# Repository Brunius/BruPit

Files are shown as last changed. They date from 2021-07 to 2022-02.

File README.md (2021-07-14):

# BruPit

A flight simulator project.

BruPit started because I went _"Gosh, Cougar MFDs are expensive for what you get"_. Since then it's grown, much more than I expected it to. I never expected to need to do proper software engineer stuff like sequence diagrams and READMEs. This repository is organised as best I can; I think it's fairly clear where stuff is, but I may be wrong. In short:

## ECAD

Contains _electrical_ CAD items. These are Circuit Diagrams and PCB layouts. All items are designed with kicad.

## MCAD

Contains _mechanical_ CAD items. These are mostly enclosures for stuff. All items are designed with Solidworks (sorry, FreeCAD - I love you, but I really wanted an assembly workbench).

## Programs

Contains the software you need. These are intended to be loaded using the Arduino IDE, though other IDEs may work.

## Documentation

Contains any documentation, mostly surrounding the software. This is stuff you _shouldn't_ need as a home user, but might want if you're modifying the software.

For any further questions or queries, you can contact me at brunius@brunius.me or Brunius#5625 on Discord.

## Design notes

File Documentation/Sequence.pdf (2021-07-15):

## Child Discovery Process (setup)

Mother | Child 1 | Child 2

childSetup()

Write 0x69
Request 2 bytes

byte 1: no. of buttons
byte 2: no. of rotaries
childSetup() | Ask what types | of input the
child has, and how many it has
| childSetup() Ask what types child has, and how many it has childSetup() | of input the
Write | 0x69
Request | 2 bytes
byte 1: no. byte 2: no. | of buttons of rotaries

This process continues until all i2c addresses have been polled. Addresses are polled from low to high, with buttons allocated on the same basis. This ensures that the same boards, connected to the same host, represent the same buttons to the OS.

1

## Data Request Process (loop)

Mother | Child 1 | Child 2

getInput()

Request 1 byte

byte 1: state of buttons

getInput() | Ask which inputs are active Child 1 has 8 buttons
| getInput() Ask which inputs are active Child 2 has 16 buttons and 1 rotary getInput()
Request | 3 bytes
byte 1: state of buttons byte 2: state of buttons byte 3: | rotary 1

This process cycles through all known active i2c addresses (discovered in child discovery process). Number of bytes varies depending on number of buttons and number of rotaries - bytes 1 to x are always state of buttons, depending on how many buttons are present. buttons x + 1 onward are rotaries

2

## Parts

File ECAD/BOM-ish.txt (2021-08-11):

Childboard 1:

	J1: Unpopulated
	J2: 1x4 2.54mm SMD Male
	J3: 1x4 2.54mm SMD Male
	J4: 1x4 2.54mm SMD Male

	U1: ATmega168V-AU

	R1: 330
	R2: 330
	R3: 330
	R4: 330	
	R5: 330

	C1: 100nF

Childboard 2 + 3:

	J1: Unpopulated
	J2: 1x4 2.54mm SMD Male
	J3: 1x4 2.54mm SMD Male
	J4: Unpopulated
	J5: 1x4 2.54mm SMD Male
	J6: 1x4 2.54mm SMD Male

	U1: ATmega168V-AU
	U2: ATmega168V-AU

	R1: 330
	R5: 330

	C1: 100nF
	C2: 100nF

Child MFD:

	J1: Unpopulated
	J2: 1x4 2.54mm SMD Male

	U1: ATmega168V-AU

	R1: 10K
	R5: 330
	R8: 330

	C4: 100nF

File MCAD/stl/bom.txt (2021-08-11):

low rate initial production:
1x frontside
1x backside

full rate:
5x frontside
5x backside
100x square button
20x long button

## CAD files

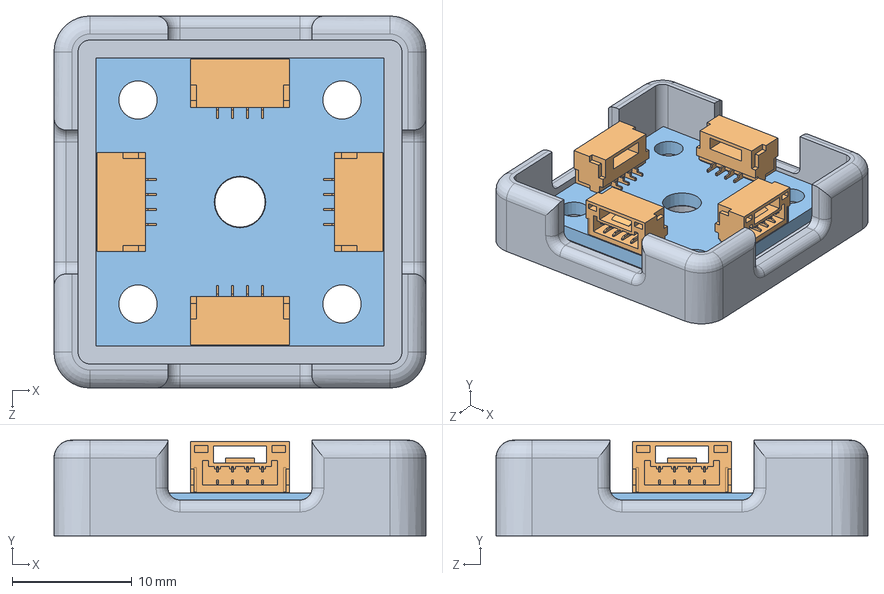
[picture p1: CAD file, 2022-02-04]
MCAD/Junction-Assembly.SLDASM
31.0 x 8.00 x 31.0 mm
Junction-Back
SOLID.step x 4
COMPOUND.step

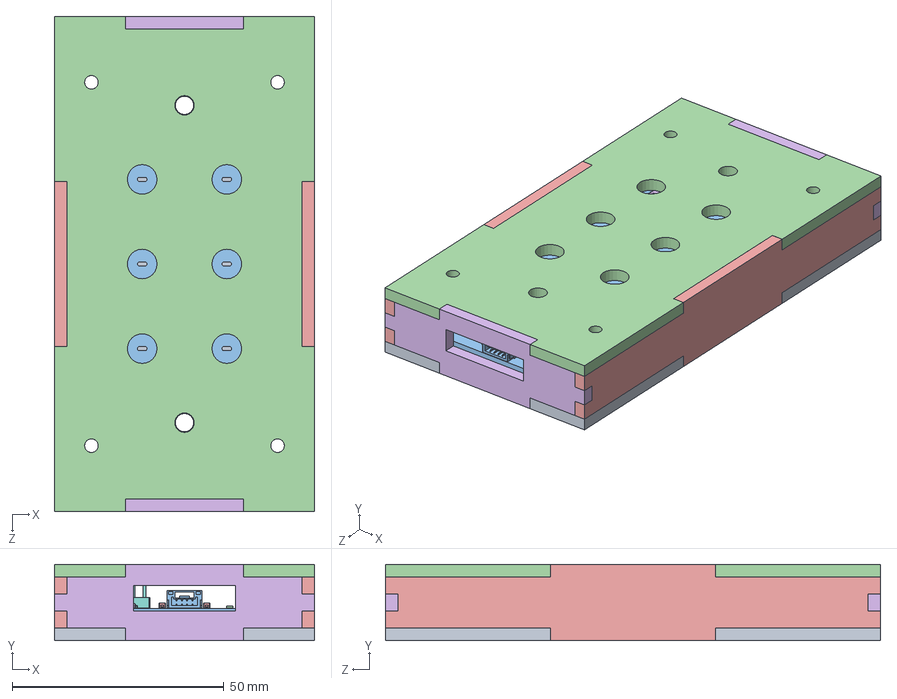
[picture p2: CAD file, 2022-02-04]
MCAD/LaserCut/SwitchBox-Assembly.SLDASM
61.5 x 18.0 x 117.0 mm
ButtonBox-Bottomplate
UFC-Washer x 2
SOLID.step x 2
SOLID-0.step
SOLID-1.step x 6
SOLID-2.step
SOLID-3.step
SOLID-4.step
SOLID-5.step
SOLID-6.step
COMPOUND.step
SwitchBox-Faceplate
SwitchBox-Sideplate x 2
SwitchBox-Topplate x 2

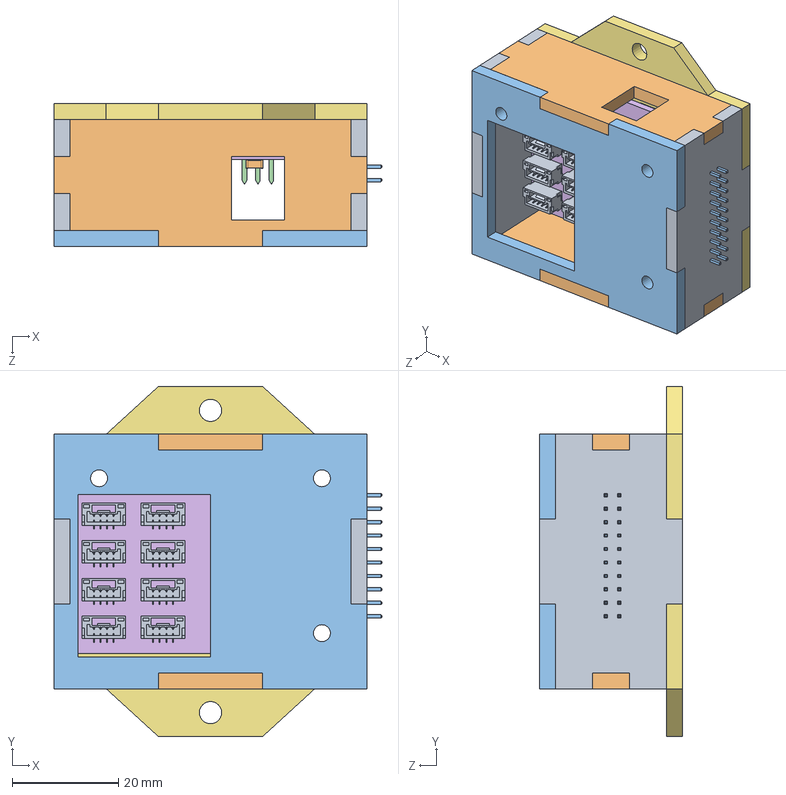
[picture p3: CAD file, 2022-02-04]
MCAD/Master-Assembly.SLDASM
61.8 x 66.0 x 27.0 mm
SOLID.step x 8
SOLID-0.step
SOLID-1.step
SOLID-2.step
SOLID-3.step x 2
COMPOUND.step
Master-Back
UFC-Washer x 2
Master-Sides x 2
Master-BottomTop x 2
Master-Front

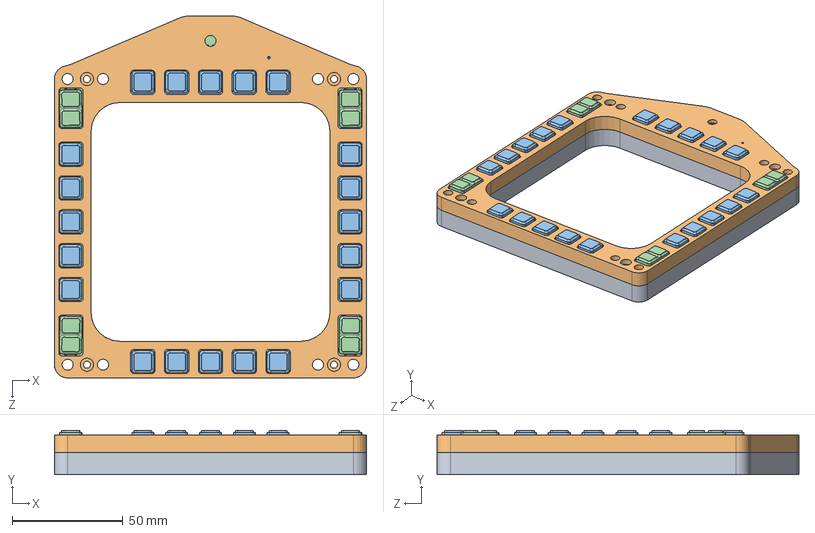
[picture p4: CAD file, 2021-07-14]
MCAD/MFD-Assembly.SLDASM
141.2 x 19.9 x 163.7 mm
Backside
Frontside
SquareButton x 20
LongButton x 4
SOLID.step
SOLID-0.step
SOLID-1.step
SOLID-2.step x 4
SOLID-3.step
SOLID-4.step x 28
SOLID-5.step
COMPOUND.step

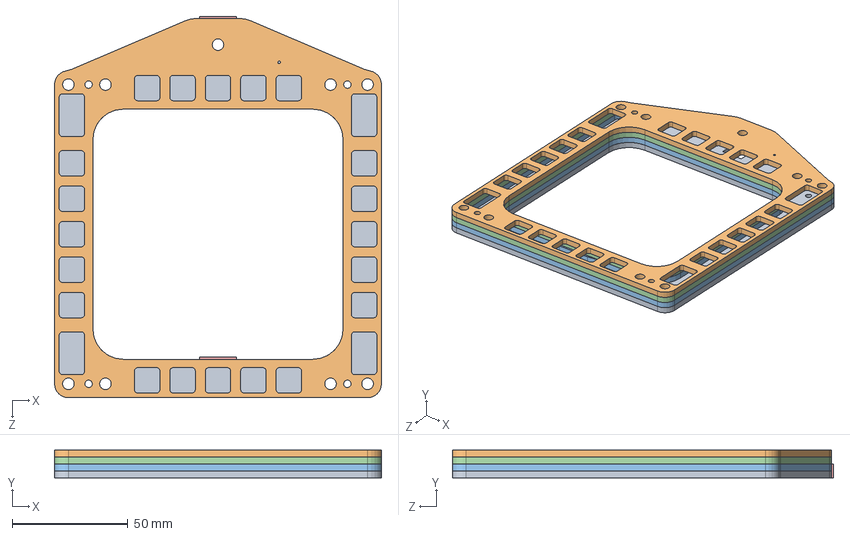
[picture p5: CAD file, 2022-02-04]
MCAD/LaserCut/MFD-Assembly.SLDASM
141.2 x 12.0 x 164.7 mm
MFD-Layer1
MFD-Layer4
MFD-Layer2
MFD-Layer3
MFD-locking x 2

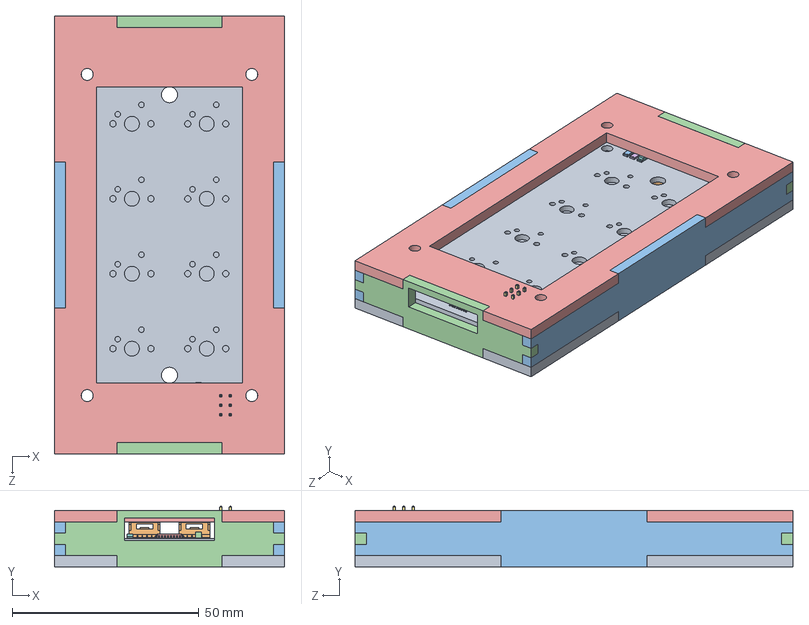
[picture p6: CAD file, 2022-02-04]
MCAD/LaserCut/ButtonBox-Assembly.SLDASM
61.5 x 16.2 x 117.0 mm
ButtonBox-Bottomplate
SOLID.step x 2
SOLID-0.step
SOLID-1.step
SOLID-2.step
SOLID-3.step
SOLID-4.step
SOLID-5.step
COMPOUND.step
UFC-Washer x 2
UFC-Sideplate x 2
ButtonBox-Topplate x 2
ButtonBox-Faceplate

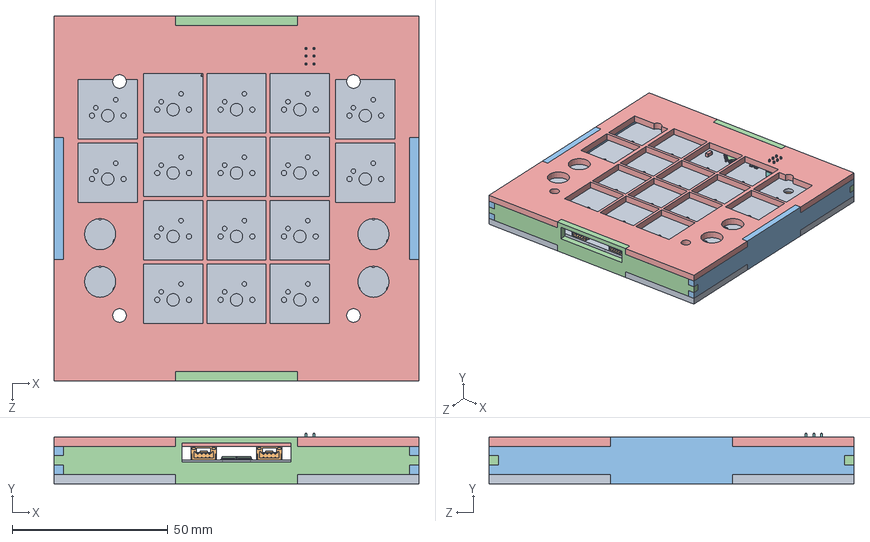
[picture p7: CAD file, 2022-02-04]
MCAD/LaserCut/UFC-Assembly.SLDASM
117.0 x 16.2 x 117.0 mm
UFC-Backplate
SOLID.step x 2
SOLID-0.step
SOLID-1.step
SOLID-2.step
SOLID-3.step x 5
SOLID-4.step
SOLID-5.step
COMPOUND.step
UFC-Washer x 4
UFC-Sideplate x 2
UFC-BottomPlate x 2
UFC-Faceplate

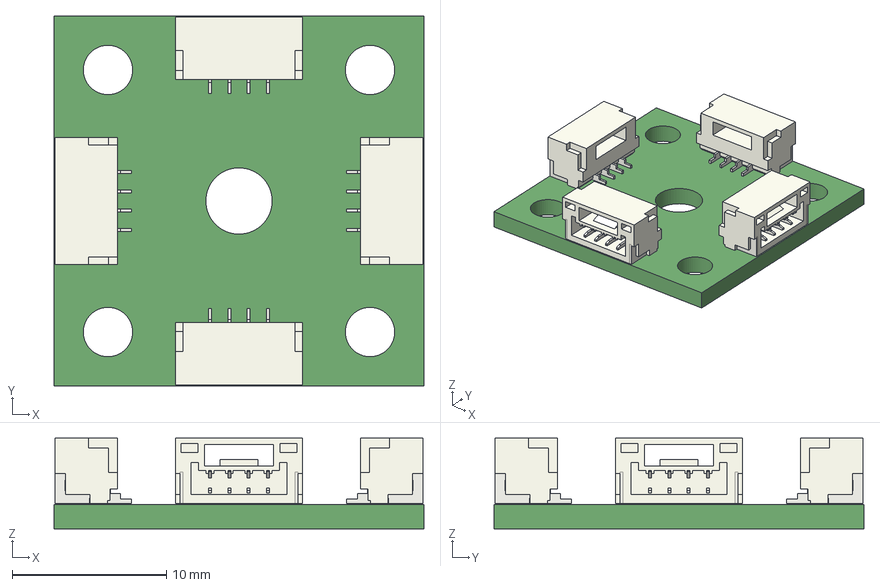
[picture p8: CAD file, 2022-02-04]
ECAD/junction/junction.step
24.0 x 24.0 x 5.89 mm

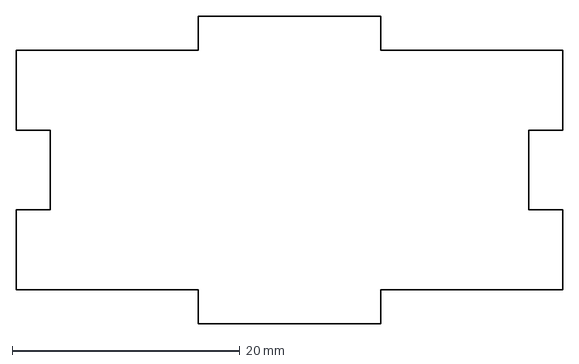
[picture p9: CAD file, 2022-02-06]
MCAD/LaserCut/Master-Sides.DXF
48.0 x 27.0 mm

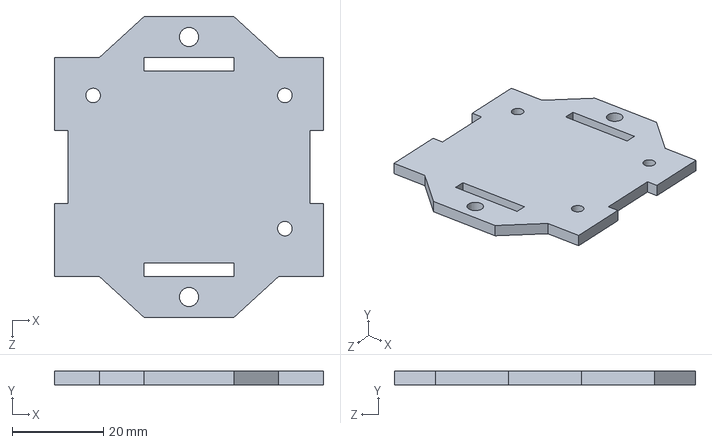
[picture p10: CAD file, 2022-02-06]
MCAD/Master-Back.SLDPRT
59.0 x 3.00 x 66.0 mm

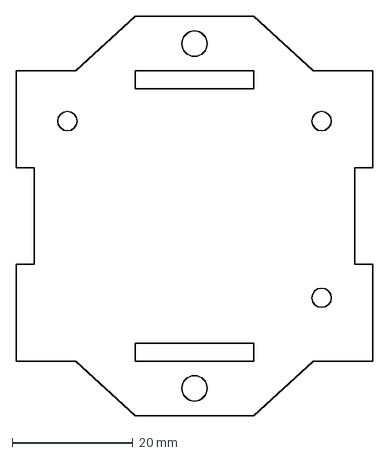
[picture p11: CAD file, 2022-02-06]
MCAD/LaserCut/Master-Back.DXF
59.0 x 66.0 mm

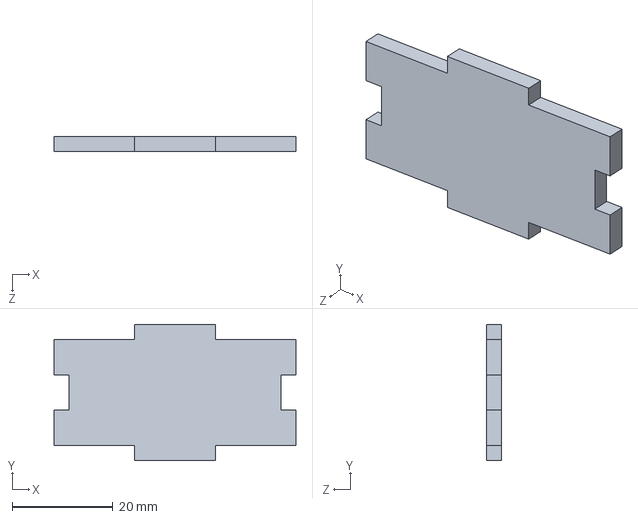
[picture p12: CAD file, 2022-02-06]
MCAD/Master-Sides.SLDPRT
48.0 x 27.0 x 3.00 mm

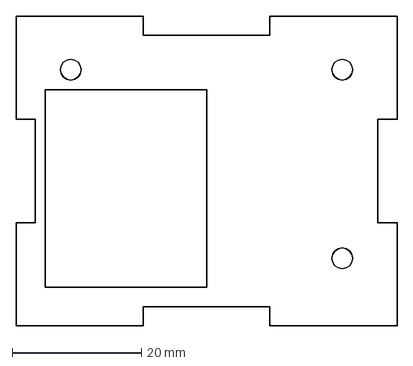
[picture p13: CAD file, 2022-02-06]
MCAD/LaserCut/Master-Front.DXF
59.0 x 48.0 mm

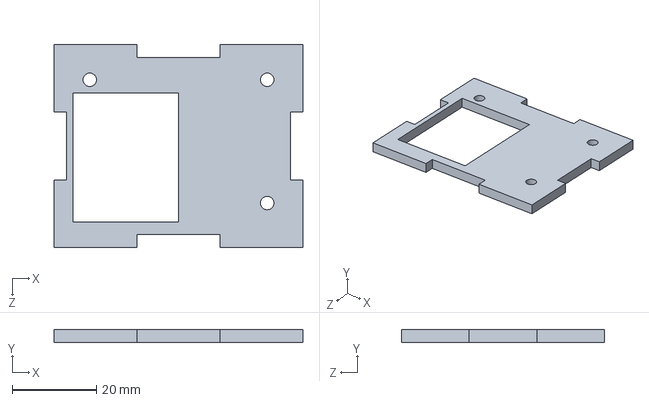
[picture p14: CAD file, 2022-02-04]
MCAD/Master-Front.SLDPRT
59.0 x 3.00 x 48.0 mm

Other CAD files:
MCAD/LaserCut/ButtonBox-Bottomplate.SLDPRT
MCAD/Master-BottomTop.SLDPRT
MCAD/Junction-Back.SLDPRT
MCAD/LaserCut/Master-BottomTop.DXF
MCAD/Backside.SLDPRT
MCAD/Frontside.SLDPRT
MCAD/LaserCut/ButtonBox-Bottomplate.DXF
MCAD/LaserCut/ButtonBox-Faceplate.DXF
MCAD/LaserCut/ButtonBox-Faceplate.SLDPRT
MCAD/LaserCut/ButtonBox-Topplate.DXF
MCAD/LaserCut/ButtonBox-Topplate.SLDPRT
MCAD/LaserCut/MFD-Layer1.DXF
MCAD/LaserCut/MFD-Layer1.SLDPRT
MCAD/LaserCut/MFD-Layer2.DXF
MCAD/LaserCut/MFD-Layer2.SLDPRT
MCAD/LaserCut/MFD-Layer3.DXF
MCAD/LaserCut/MFD-Layer3.SLDPRT
MCAD/LaserCut/MFD-Layer4.DXF
MCAD/LaserCut/MFD-Layer4.SLDPRT
MCAD/LaserCut/MFD-locking.DXF
MCAD/LaserCut/MFD-locking.SLDPRT
MCAD/LaserCut/SwitchBox-Faceplate.DXF
MCAD/LaserCut/SwitchBox-Faceplate.SLDPRT
MCAD/LaserCut/SwitchBox-Sideplate.DXF
MCAD/LaserCut/SwitchBox-Sideplate.SLDPRT
MCAD/LaserCut/SwitchBox-Topplate.DXF
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

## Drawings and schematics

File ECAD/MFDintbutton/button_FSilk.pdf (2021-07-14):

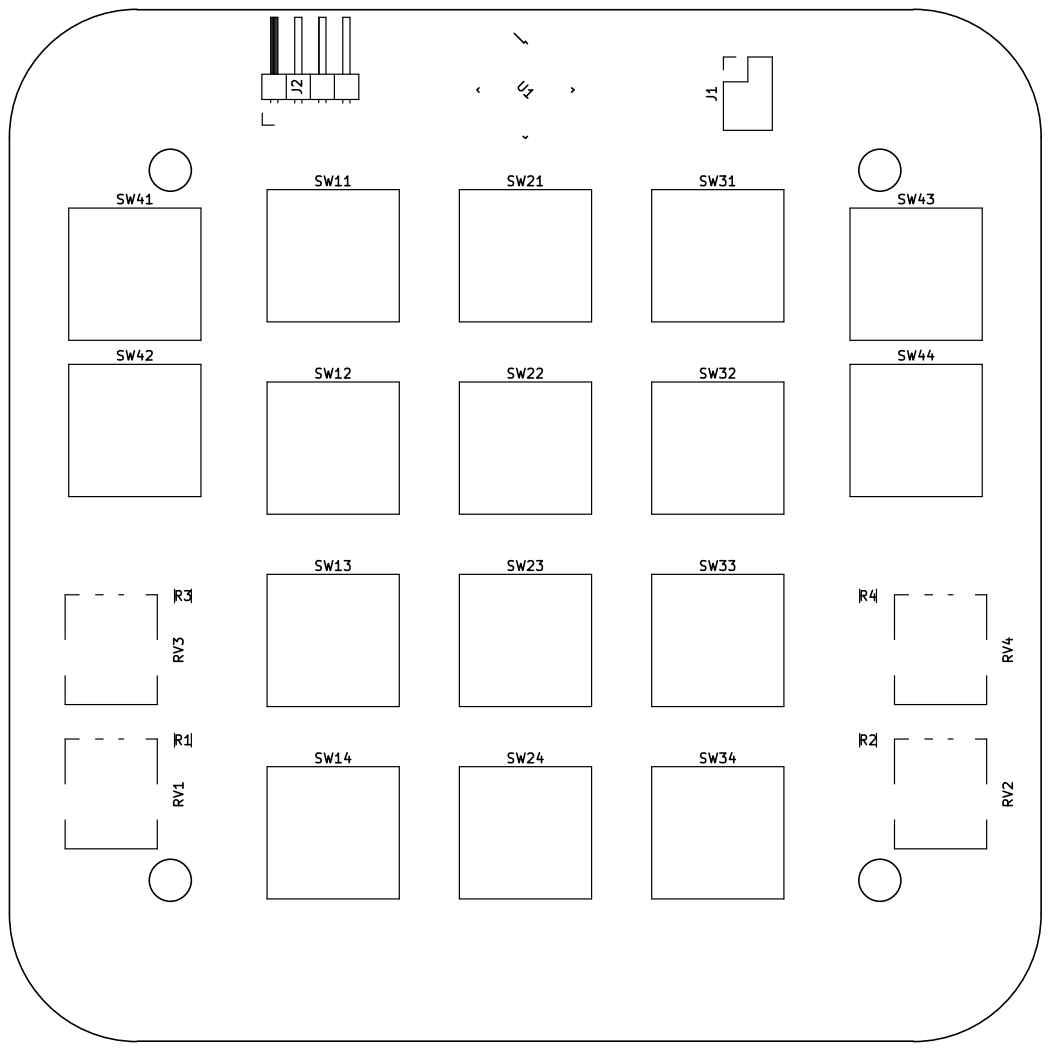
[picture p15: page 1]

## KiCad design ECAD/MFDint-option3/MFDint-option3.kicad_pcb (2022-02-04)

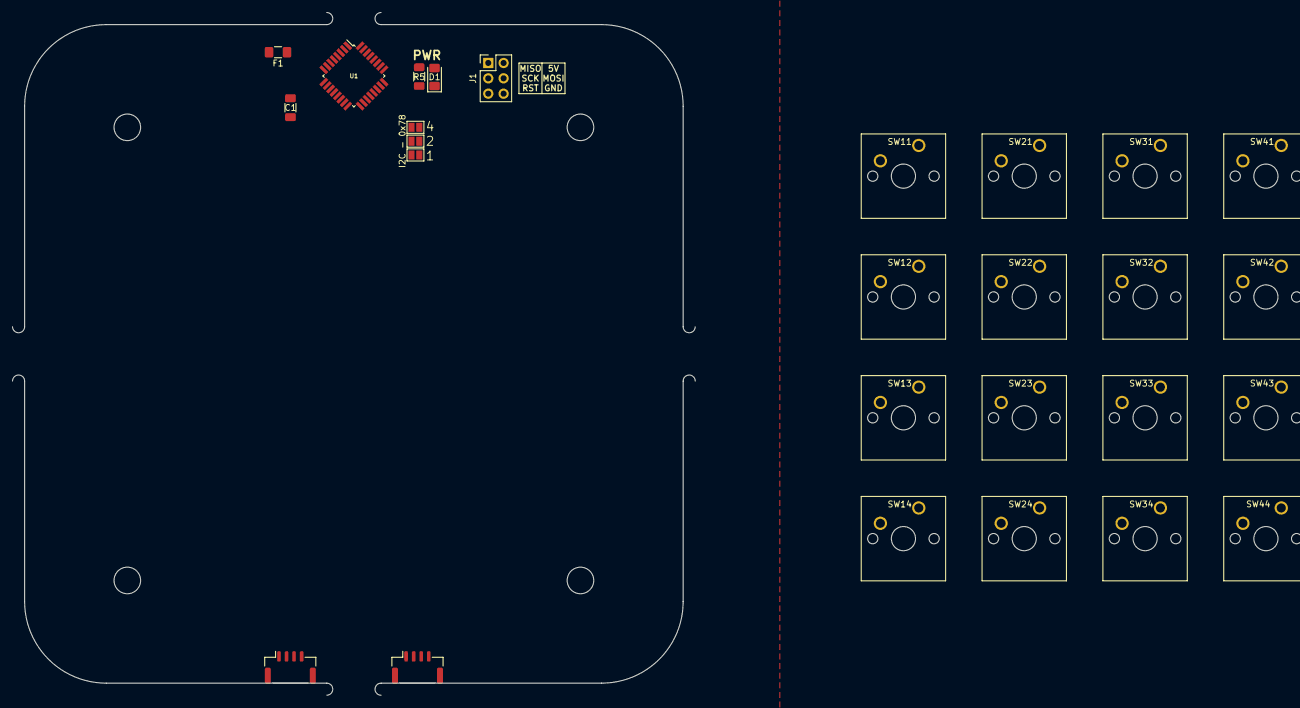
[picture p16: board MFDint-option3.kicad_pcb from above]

Board: 2 copper layers, 113.0 x 113.0 mm, 27 parts (0 on the bottom side), 22 nets, no tracks yet.

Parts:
C1: 100nF; C_1206_3216Metric_Pad1.33x1.80mm_HandSolder
D1: LED; LED_1206_3216Metric_Pad1.42x1.75mm_HandSolder
F1: Polyfuse; Fuse_1206_3216Metric_Pad1.42x1.75mm_HandSolder
J1: Conn_02x03_Odd_Even; PinHeader_2x03_P2.54mm_Vertical
J2, J3: Conn_01x04; JST_GH_SM04B-GHS-TB_1x04-1MP_P1.25mm_Horizontal
JP1, JP2, JP3: Jumper_NO_Small; SolderJumper-2_P1.3mm_Open_Pad1.0x1.5mm
R5: 330; R_1206_3216Metric_Pad1.30x1.75mm_HandSolder
SW11, SW12, SW13, SW14, SW21, SW22, SW23, SW24, SW31, SW32, SW33, SW34, SW41, SW42, SW43, SW44: SW_Push; SW_Cherry_MX_1.00u_PCB
U1: ATmega328P-AU; TQFP-32_7x7mm_P0.8mm

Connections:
+5V: D1.2, F1.1, J1.2, U1.4, U1.6, U1.18
/1line: JP1.1, U1.12
/2line: JP2.1, U1.13
/4line: JP3.1, U1.14
/COL1: SW11.2, SW12.2, SW13.2, SW14.2, U1.32
/COL2: SW21.2, SW22.2, SW23.2, SW24.2, U1.31
/COL3: SW31.2, SW32.2, SW33.2, SW34.2, U1.30
/COL4: SW41.2, SW42.2, SW43.2, SW44.2, U1.11
/ROW1: SW11.1, SW21.1, SW31.1, SW41.1, U1.1
/ROW2: SW12.1, SW22.1, SW32.1, SW42.1, U1.2
/ROW3: SW13.1, SW23.1, SW33.1, SW43.1, U1.9
/ROW4: SW14.1, SW24.1, SW34.1, SW44.1, U1.10
GND: C1.2, J1.6, J2.4, J3.4, JP1.2, JP2.2, JP3.2, R5.1, U1.3, U1.5, U1.21
MISO: J1.1, U1.16
MOSI: J1.4, U1.15
unnamed: C1.1, U1.20
unnamed: D1.1, R5.2
unnamed: F1.2, J2.1, J3.1
RESET: J1.5, U1.29
SCK: J1.3, U1.17
SCL: J2.2, J3.2, U1.28
SDA: J2.3, J3.3, U1.27

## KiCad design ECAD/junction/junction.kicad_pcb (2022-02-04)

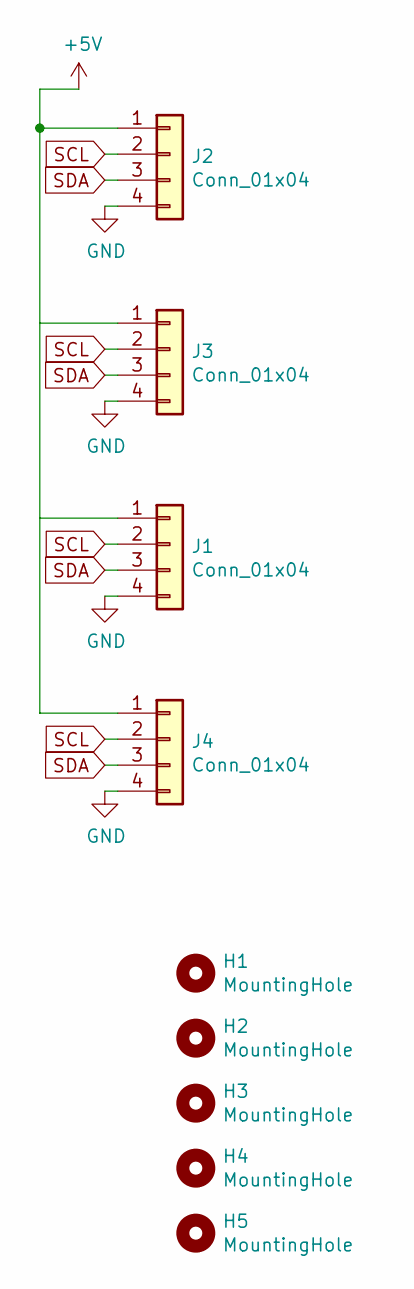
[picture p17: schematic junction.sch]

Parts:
H1, H2, H3, H4: MountingHole; MountingHole_3.2mm_M3
H5: MountingHole; MountingHole_4.3mm_M4
J1, J2, J3, J4: Conn_01x04; JST_GH_SM04B-GHS-TB_1x04-1MP_P1.25mm_Horizontal

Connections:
+5V: J1.1, J2.1, J3.1, J4.1
GND: J1.4, J2.4, J3.4, J4.4
SCL: J1.2, J2.2, J3.2, J4.2
SDA: J1.3, J2.3, J3.3, J4.3

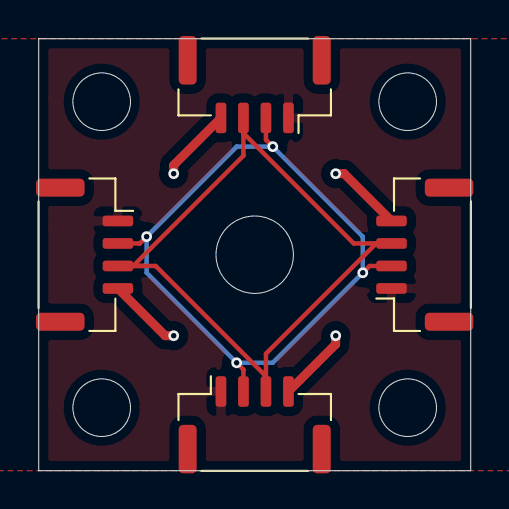
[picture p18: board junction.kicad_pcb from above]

Board: 2 copper layers, 24.0 x 24.0 mm, 9 parts (0 on the bottom side), 4 nets.

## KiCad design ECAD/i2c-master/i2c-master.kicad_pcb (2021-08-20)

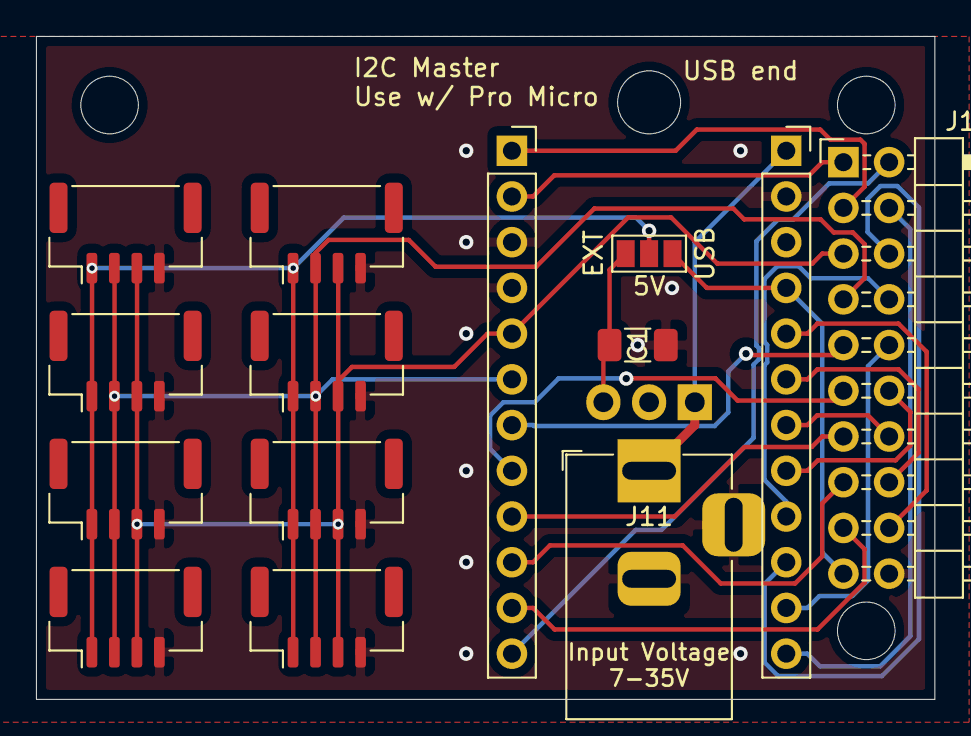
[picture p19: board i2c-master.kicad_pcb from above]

Board: 2 copper layers, 49.9 x 36.8 mm, 18 parts (1 on the bottom side), 23 nets.

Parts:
5V: Jumper_NC_Dual; SolderJumper-3_P1.3mm_Open_Pad1.0x1.5mm_NumberLabels
C1: 100nF; C_1206_3216Metric_Pad1.33x1.80mm_HandSolder
H1, H2, H4: MountingHole; MountingHole_3.2mm_M3_ISO7380
J1, J6: Conn_01x12_Female; PinSocket_1x12_P2.54mm_Vertical
J2, J3, J4, J5, J7, J8, J9, J10: Conn_01x04; JST_GH_BM04B-GHS-TBT_1x04-1MP_P1.25mm_Vertical
J11: Barrel_Jack; BarrelJack_Horizontal
J12: Conn_02x10_Odd_Even; PinHeader_2x10_P2.54mm_Horizontal
U1: L7805; TO-220-3_Horizontal_TabDown

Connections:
!IO3-SCL: J1.6, J2.2, J3.2, J4.2, J5.2, J7.2, J8.2, J9.2, J10.2, J12.7
!IO5: J1.8, J12.11
!IO6-A7: J1.9, J12.13
!IO9-A9: J1.12, J12.2
!IO10-A10: J6.12, J12.4
+5V: 5V.2, J2.1, J3.1, J4.1, J5.1, J7.1, J8.1, J9.1, J10.1
GND: C1.2, J1.3, J1.4, J2.4, J3.4, J4.4, J5.4, J6.2, J7.4, J8.4, J9.4, J10.4, J11.2, J11.3, J12.20, U1.2
IO0-RX: J1.2, J12.1
IO1-TX: J1.1, J12.3
IO2-SDA: J1.5, J2.3, J3.3, J4.3, J5.3, J7.3, J8.3, J9.3, J10.3, J12.5
IO4-A6: J1.7, J12.9
IO7: J1.10, J12.15
IO8-A8: J1.11, J12.17
IO14-MISO: J6.10, J12.6
IO15-SCK: J6.9, J12.8
IO16-MOSI: J6.11, J12.10
IO18-A0: J6.8, J12.12
IO19-A1: J6.7, J12.14
IO20-A2: J6.6, J12.16
IO21-A3: J6.5, J12.18
unnamed: 5V.3, C1.1, U1.3
VCC: 5V.1, J6.4, J12.19
VIN: J6.1, J11.1, U1.1

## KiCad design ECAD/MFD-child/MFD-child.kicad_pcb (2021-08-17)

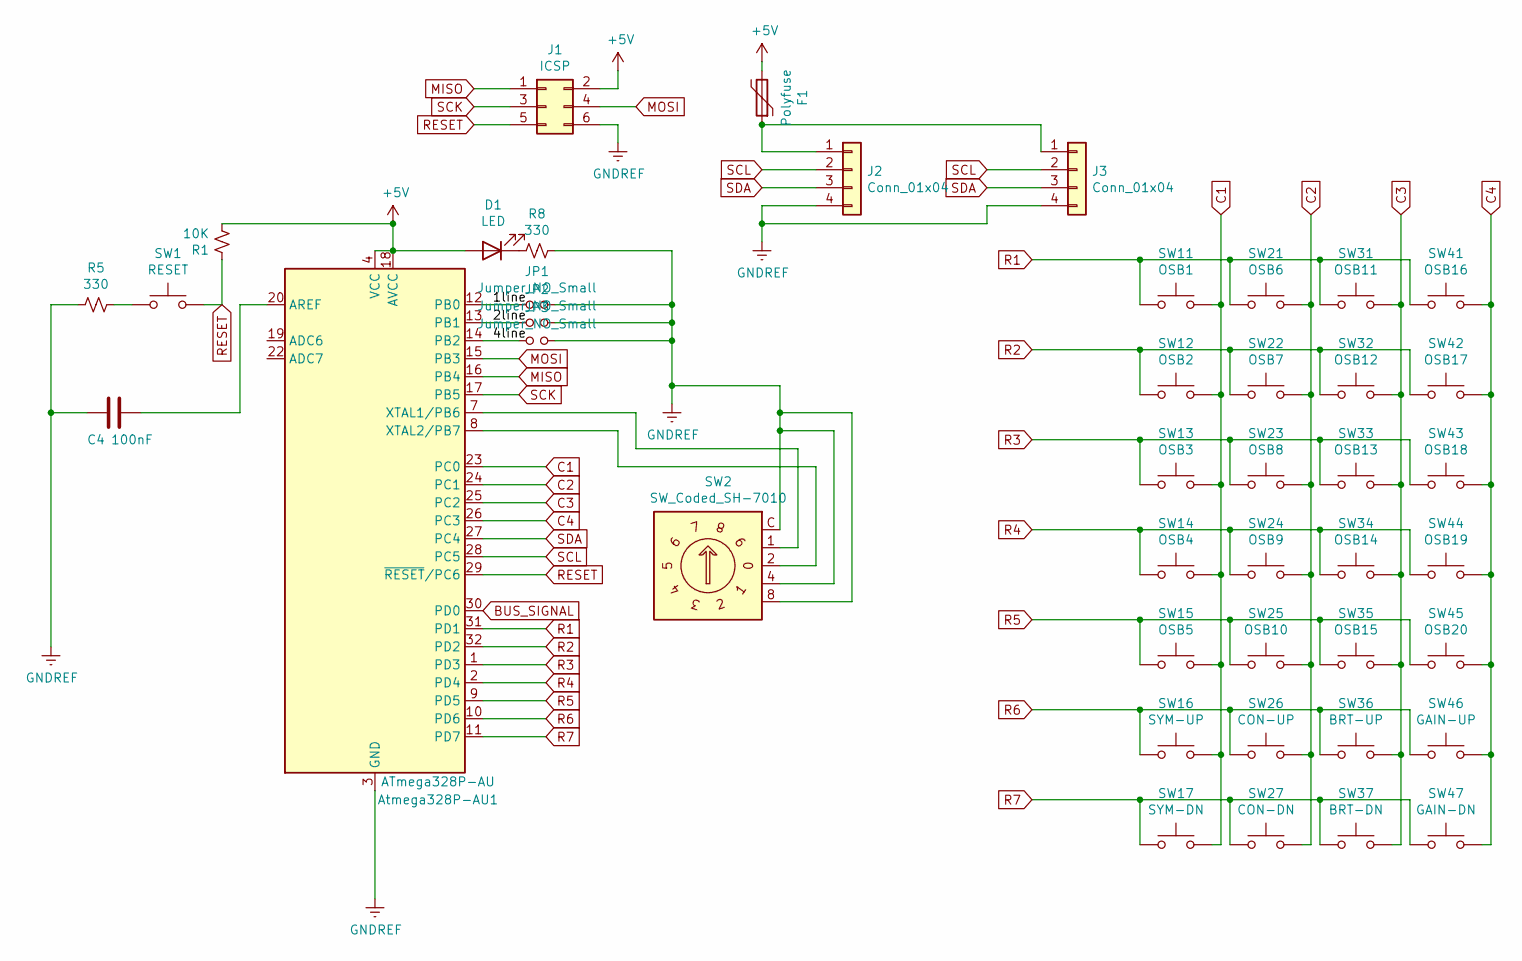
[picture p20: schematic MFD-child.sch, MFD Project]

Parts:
Atmega328P-AU1: ATmega328P-AU; TQFP-32_7x7mm_P0.8mm
C4: 100nF; C_1206_3216Metric_Pad1.33x1.80mm_HandSolder
D1: LED; LED_1206_3216Metric_Castellated
F1: Polyfuse; Fuse_1206_3216Metric_Pad1.42x1.75mm_HandSolder
J1: ICSP; PinHeader_2x03_P2.54mm_Vertical
J2, J3: Conn_01x04; JST_GH_SM04B-GHS-TB_1x04-1MP_P1.25mm_Horizontal
JP1, JP2, JP3: Jumper_NO_Small; SolderJumper-2_P1.3mm_Open_Pad1.0x1.5mm
R1: 10K; C_1206_3216Metric_Pad1.33x1.80mm_HandSolder
R5, R8: 330; C_1206_3216Metric_Pad1.33x1.80mm_HandSolder
SW1: RESET; SW_DIP_SPSTx01_Slide_6.7x4.1mm_W8.61mm_P2.54mm_LowProfile
SW2: SW_Coded_SH-7010; Nidec_Copal_SH-7010B
SW11: OSB1; SW_SPST_PTS645
SW12: OSB2; SW_SPST_PTS645
SW13: OSB3; SW_SPST_PTS645
SW14: OSB4; SW_SPST_PTS645
SW15: OSB5; SW_SPST_PTS645
SW16: SYM-UP; SW_SPST_PTS645
SW17: SYM-DN; SW_SPST_PTS645
SW21: OSB6; SW_SPST_PTS645
SW22: OSB7; SW_SPST_PTS645
SW23: OSB8; SW_SPST_PTS645
SW24: OSB9; SW_SPST_PTS645
SW25: OSB10; SW_SPST_PTS645
SW26: CON-UP; SW_SPST_PTS645
SW27: CON-DN; SW_SPST_PTS645
SW31: OSB11; SW_SPST_PTS645
SW32: OSB12; SW_SPST_PTS645
SW33: OSB13; SW_SPST_PTS645
SW34: OSB14; SW_SPST_PTS645
SW35: OSB15; SW_SPST_PTS645
SW36: BRT-UP; SW_SPST_PTS645
SW37: BRT-DN; SW_SPST_PTS645
SW41: OSB16; SW_SPST_PTS645
SW42: OSB17; SW_SPST_PTS645
SW43: OSB18; SW_SPST_PTS645
SW44: OSB19; SW_SPST_PTS645
SW45: OSB20; SW_SPST_PTS645
SW46: GAIN-UP; SW_SPST_PTS645
SW47: GAIN-DN; SW_SPST_PTS645

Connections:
+5V: Atmega328P-AU1.4 (VCC), Atmega328P-AU1.6 (VCC), Atmega328P-AU1.18 (AVCC), D1.2 (A), F1.2, J1.2, R1.2
/1line: Atmega328P-AU1.12 (PB0), JP1.1
/2line: Atmega328P-AU1.13 (PB1), JP2.1
/4line: Atmega328P-AU1.14 (PB2), JP3.1
BUS_SIGNAL: Atmega328P-AU1.30 (PD0)
C1: Atmega328P-AU1.23 (PC0), SW11.2, SW12.2, SW13.2, SW14.2, SW15.2, SW16.2, SW17.2
C2: Atmega328P-AU1.24 (PC1), SW21.2, SW22.2, SW23.2, SW24.2, SW25.2, SW26.2, SW27.2
C3: Atmega328P-AU1.25 (PC2), SW31.2, SW32.2, SW33.2, SW34.2, SW35.2, SW36.2, SW37.2
C4: Atmega328P-AU1.26 (PC3), SW41.2, SW42.2, SW43.2, SW44.2, SW45.2, SW46.2, SW47.2
GNDREF: Atmega328P-AU1.3 (GND), Atmega328P-AU1.5 (GND), Atmega328P-AU1.21 (GND), C4.2, J1.6, J2.4, J3.4, JP1.2, JP2.2, JP3.2, R5.2, R8.1, SW2.4, SW2.8, SW2.C
MISO: Atmega328P-AU1.16 (PB4), J1.1
MOSI: Atmega328P-AU1.15 (PB3), J1.4
unnamed: Atmega328P-AU1.7 (XTAL1/PB6), SW2.1
unnamed: Atmega328P-AU1.8 (XTAL2/PB7), SW2.2
unnamed: Atmega328P-AU1.20 (AREF), C4.1
unnamed: D1.1 (K), R8.2
unnamed: F1.1, J2.1, J3.1
unnamed: R5.1, SW1.1
R1: Atmega328P-AU1.31 (PD1), SW11.1, SW21.1, SW31.1, SW41.1
R2: Atmega328P-AU1.32 (PD2), SW12.1, SW22.1, SW32.1, SW42.1
R3: Atmega328P-AU1.1 (PD3), SW13.1, SW23.1, SW33.1, SW43.1
R4: Atmega328P-AU1.2 (PD4), SW14.1, SW24.1, SW34.1, SW44.1
R5: Atmega328P-AU1.9 (PD5), SW15.1, SW25.1, SW35.1, SW45.1
R6: Atmega328P-AU1.10 (PD6), SW16.1, SW26.1, SW36.1, SW46.1
R7: Atmega328P-AU1.11 (PD7), SW17.1, SW27.1, SW37.1, SW47.1
RESET: Atmega328P-AU1.29 (~RESET~/PC6), J1.5, R1.1, SW1.2
SCK: Atmega328P-AU1.17 (PB5), J1.3
SCL: Atmega328P-AU1.28 (PC5), J2.2, J3.2
SDA: Atmega328P-AU1.27 (PC4), J2.3, J3.3

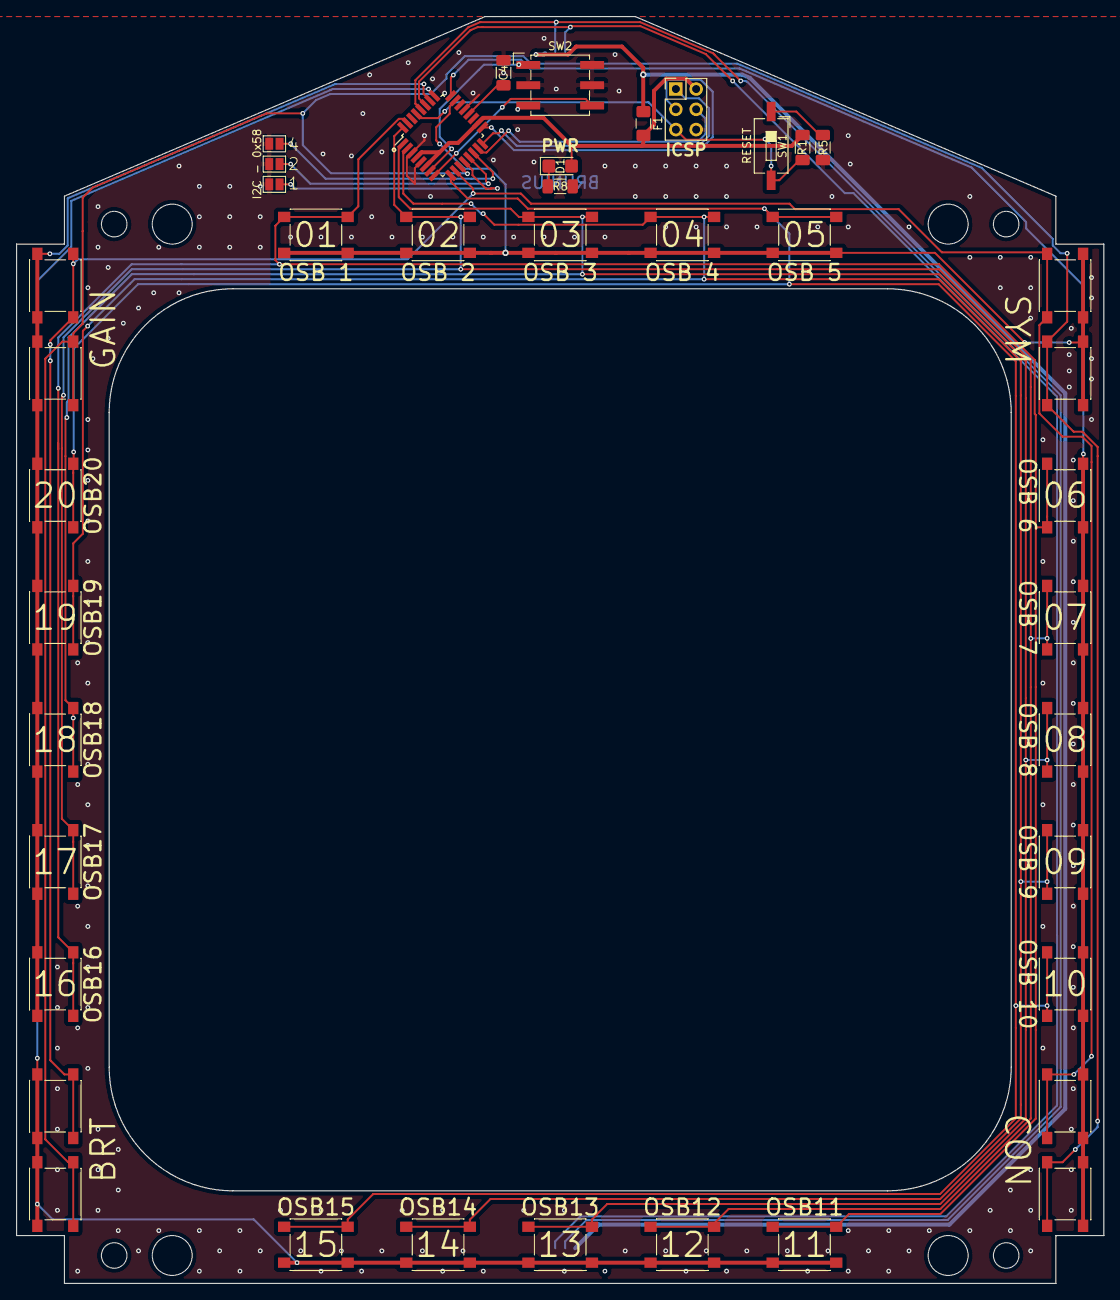
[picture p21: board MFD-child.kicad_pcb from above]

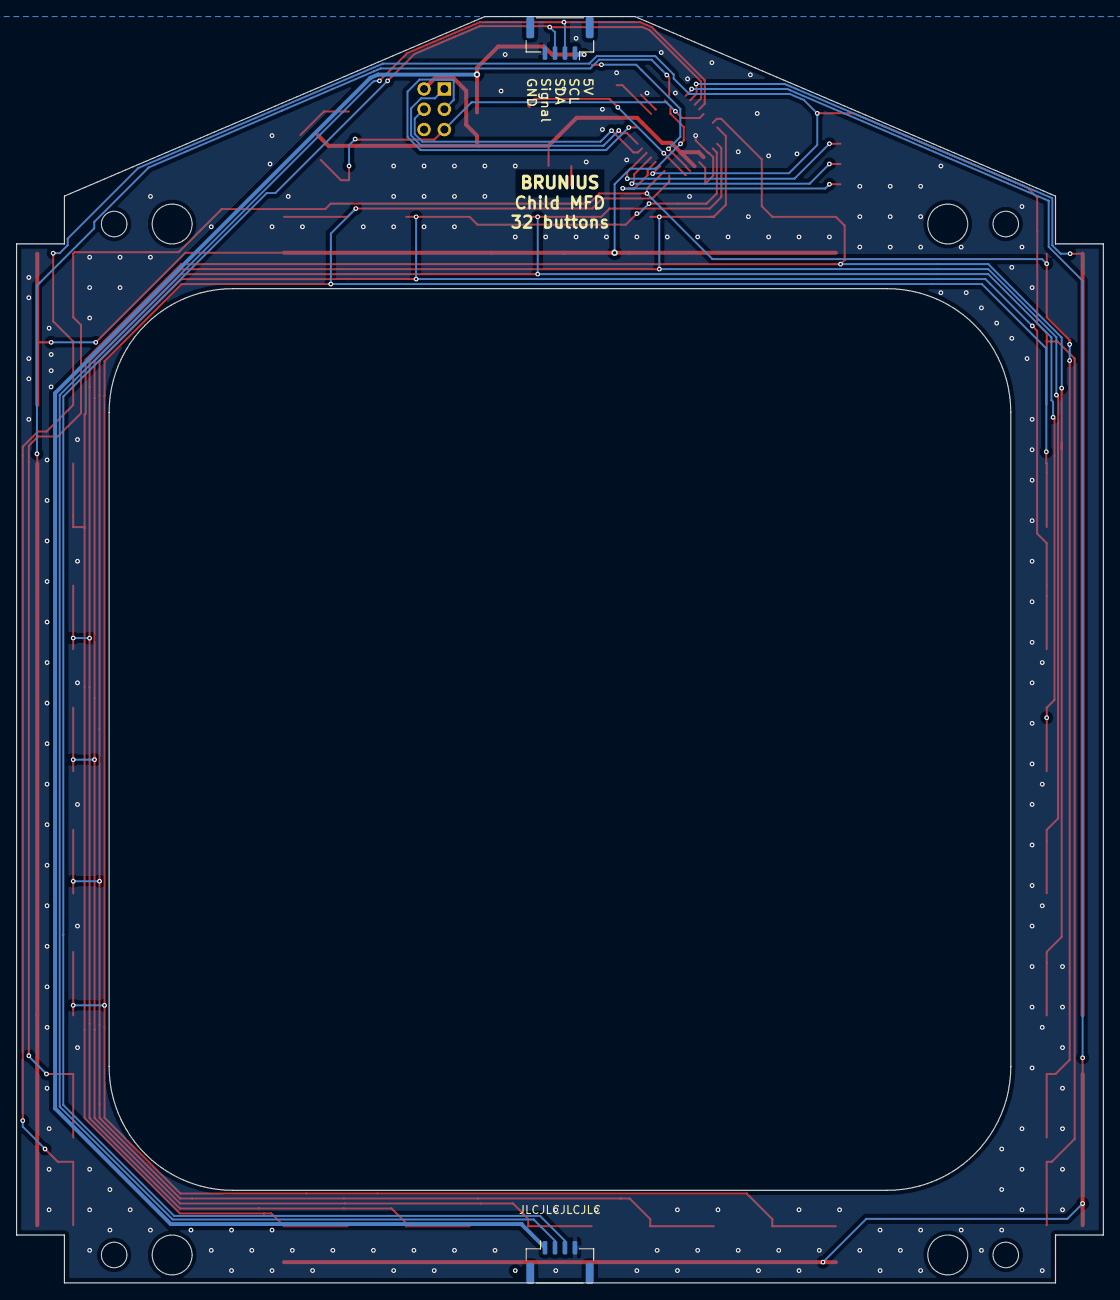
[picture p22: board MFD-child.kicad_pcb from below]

Board: 2 copper layers, 136.2 x 158.7 mm, 43 parts (2 on the bottom side), 28 nets.

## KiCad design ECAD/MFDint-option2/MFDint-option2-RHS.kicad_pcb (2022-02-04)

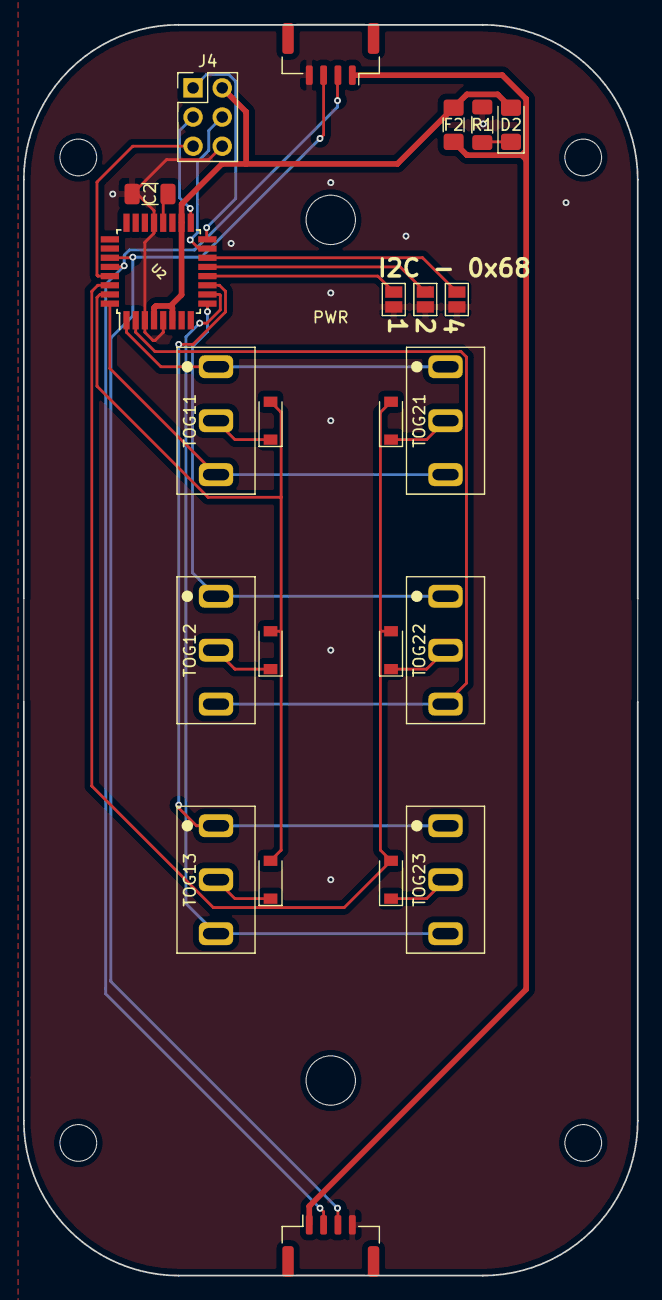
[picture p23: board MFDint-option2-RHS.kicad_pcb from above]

Board: 2 copper layers, 53.5 x 109.0 mm, 29 parts (0 on the bottom side), 28 nets.

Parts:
C2: 100nF; C_1206_3216Metric_Pad1.33x1.80mm_HandSolder
D2: LED; LED_1206_3216Metric_Pad1.42x1.75mm_HandSolder
D11, D12, D13, D21, D22, D23: D; D_SOD-123
F2: Polyfuse; Fuse_1206_3216Metric_Pad1.42x1.75mm_HandSolder
H3, H4: MountingHole; MountingHole_4.3mm_M4
H9, H10, H11, H12: MountingHole; MountingHole_3.2mm_M3
J4: Conn_02x03_Odd_Even; PinHeader_2x03_P2.54mm_Vertical
J5, J6: Conn_01x04; JST_GH_SM04B-GHS-TB_1x04-1MP_P1.25mm_Horizontal
JP4, JP5, JP6: Jumper_NO_Small; SolderJumper-2_P1.3mm_Open_Pad1.0x1.5mm
R1: 330; R_1206_3216Metric_Pad1.30x1.75mm_HandSolder
TOG11, TOG12, TOG13, TOG21, TOG22, TOG23: SW_SPDT_MSM; SPDT-CentreOff
U2: ATmega328P-AU; TQFP-32_7x7mm_P0.8mm

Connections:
/1line2: JP4.1, U2.12
/2line2: JP5.1, U2.13
/4line2: JP6.1, U2.14
/COL12: D11.2, D12.2, D13.2, U2.31
/COL22: D21.2, D22.2, D23.2, U2.30
/ROW12: TOG11.3, TOG21.3, U2.32
/ROW22: TOG11.1, TOG21.1, U2.1
/ROW32: TOG12.3, TOG22.3, U2.2
/ROW42: TOG12.1, TOG22.1, U2.9
/ROW52: TOG13.3, TOG23.3, U2.10
/ROW62: TOG13.1, TOG23.1, U2.11
GNDREF: C2.2, J4.6, J5.4, J6.4, JP4.2, JP5.2, JP6.2, R1.2, U2.3, U2.5, U2.21
MISO2: J4.1, U2.16
MOSI2: J4.4, U2.15
unnamed: C2.1, U2.20
unnamed: D2.1, R1.1
unnamed: D11.1, TOG11.2
unnamed: D12.1, TOG12.2
unnamed: D13.1, TOG13.2
unnamed: D21.1, TOG21.2
unnamed: D22.1, TOG22.2
unnamed: D23.1, TOG23.2
unnamed: F2.2, J5.1, J6.1
RESET2: J4.5, U2.29
SCK2: J4.3, U2.17
SCL2: J5.2, J6.2, U2.28
SDA2: J5.3, J6.3, U2.27
VCC: D2.2, F2.1, J4.2, U2.4, U2.6, U2.18

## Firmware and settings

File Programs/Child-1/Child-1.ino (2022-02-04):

#include <Wire.h>

#define NUM_COLS 4

#define COL_1 2
#define COL_2 1
#define COL_3 0
#define COL_4 7

#define NUM_ROWS 4

#define ROW_1 3
#define ROW_2 4
#define ROW_3 5
#define ROW_4 6

byte rowPins[NUM_ROWS] = {ROW_1, ROW_2, ROW_3, ROW_4};
byte colPins[NUM_COLS] = {COL_1, COL_2, COL_3, COL_4};

union buttonStorage {
  uint16_t i;
  byte b[2];
};

union rotaryStorage {
  byte b[4];
};

union buttonStorage buttonState;
union rotaryStorage rotaryState;


#define I2C_BASE 0x78

#define I2C_1_LINE 8
#define I2C_2_LINE 9
#define I2C_4_LINE 10

#define NUMBER_BUTTONS 16
#define NUMBER_ROTARIES 4

boolean returnInputs = false;

void i2c_setup() {
  pinMode(I2C_4_LINE, INPUT_PULLUP);
  pinMode(I2C_2_LINE, INPUT_PULLUP);
  pinMode(I2C_1_LINE, INPUT_PULLUP);

  byte address = I2C_BASE;

  address += 4*!digitalRead(I2C_4_LINE);
  address += 2*!digitalRead(I2C_2_LINE);
  address += 1*!digitalRead(I2C_1_LINE);
  
  Wire.begin(address);
  Wire.onRequest(requestEvent);
  Wire.onReceive(receiveEvent);
}

void matrix_setup() {
  for (int i = 0; i < NUM_COLS; i++) {
    pinMode(colPins[i], OUTPUT);
  }
  for (int i = 0; i < NUM_ROWS; i++) {
    pinMode(rowPins[i], INPUT_PULLUP);
  }
  buttonState.i = 0;
}

void read_buttons() {
  uint8_t buttonIndex = 0;
  for (int i = 0; i < NUM_COLS; i++) {
    //COLUMNS
    digitalWrite(colPins[i], LOW);
    for (int j = 0; j < NUM_ROWS; j++) {
      //ROWS
      if(!digitalRead(rowPins[j])) {
        buttonState.i |= (uint32_t)1 << buttonIndex;
      } else {
        buttonState.i &= ~((uint32_t)1 << buttonIndex);
      }
      buttonIndex++;
    }
    digitalWrite(colPins[i], HIGH);
  }
}

void read_rotaries() {
  rotaryState.b[0] = 255-analogRead(A0)/4;
  rotaryState.b[1] = 255-analogRead(A1)/4;
  rotaryState.b[2] = 255-analogRead(A2)/4;
  rotaryState.b[3] = 255-analogRead(A3)/4;
}

void setup() {
  // put your setup code here, to run once:
  i2c_setup();
  matrix_setup();
}

void loop() {
  // put your main code here, to run repeatedly:
  //delay(10);
  read_buttons();
  read_rotaries();
}

void requestEvent() {
  if (returnInputs) {
    //Return number of inputs provided by this child board
    Wire.write(NUMBER_BUTTONS);
    Wire.write(NUMBER_ROTARIES);
    returnInputs = false;
  } else {
    //Return state of inputs. Provide buttons as byte-grouped 0/1, provide rotaries as 0-255
    //example - Wire.write(0b01010101); is 8 buttons, on/off/on/off/on/off/on/off
    Wire.write(buttonState.b, 2);
    Wire.write(rotaryState.b, 4);
  }
}

void receiveEvent(int receiveBytes) {
  //The expectation is that if we receive any bytes at all, it's putting us into "how many inputs do you provide?" mode.
  //Still, we'll check.
  if (Wire.read() == 0x69) {
    returnInputs = true;
  }
}

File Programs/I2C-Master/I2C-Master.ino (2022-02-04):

#include <Wire.h>
#include <Joystick.h>

#define HID_ID 0x03

Joystick_ Joystick(HID_ID, JOYSTICK_TYPE_GAMEPAD, 128, 0);

#define PING_FREQUENCY 5000 //5 seconds

byte addressList[16][3];  //16 addresses is 128 buttons, assuming 8 buttons per address. That seems a reasonable maximum.
                          //[0] is the address of the child
                          //[1] is the number of buttons
                          //[2] is the number of rotaries
byte addressLength = 0;

void ping_bus() {
  addressLength = 0;
  for (byte address = 0x08; address <= 0x7F; address++) {
    //0x00 -> 0x07 are reserved addresses
    //0x7F is the highest possible address
    //Therefore we ping 0x08 -> 0x7F
    Wire.beginTransmission(address);
    Wire.write(0x69);
    byte returnValue = Wire.endTransmission();

    if (returnValue == 0) {
      //Found a device!
      Wire.requestFrom(address, 2);
      addressList[addressLength][0] = address;
      addressList[addressLength][1] = Wire.read();
      addressList[addressLength][2] = Wire.read();
      addressLength++;
    }
  }
}

void writeJoystickValue(int value, int index) {
  /*
   * index mappings:
   *    0 = X
   *    1 = Y
   *    2 = Z
   *    3 = RX
   *    4 = RY
   *    5 = RZ
   */
   switch (index){
    case 0:
      Joystick.setXAxis(value);
      break;
    case 1:
      Joystick.setYAxis(value);
      break;
    case 2:
      Joystick.setZAxis(value);
      break;
    case 3:
      Joystick.setRxAxis(value);
      break;
    case 4:
      Joystick.setRyAxis(value);
      break;
    case 5:
      Joystick.setRzAxis(value);
      break;
   }
   
}

void setupJoysticks() {
  Joystick.setXAxisRange(0, 255);
  Joystick.setYAxisRange(0, 255);
  Joystick.setZAxisRange(0, 255);
  Joystick.setRxAxisRange(0, 255);
  Joystick.setRyAxisRange(0, 255);
  Joystick.setRzAxisRange(0, 255);
}

void setup() {
  Serial.begin(9600);
  Wire.begin();
  delay(5000);  //Allow other devices time to come up. 
  ping_bus();

  Joystick.begin();
  setupJoysticks();
  Serial.println("Addresses:");
  for (int i = 0; i < addressLength; i++) {
    Serial.print("  Found device at 0x");
    Serial.print(addressList[i][0], HEX);
    Serial.print(" with ");
    Serial.print(addressList[i][1]);
    Serial.println(" buttons");
  }
  Serial.println("End list");
//  while (!Serial.available()){};
}

int millisecondsSincePing = 0;

void loop() {
  uint8_t buttonIndex = 0;
  uint8_t rotaryIndex = 0;
  for (uint8_t i = 0; i < addressLength; i++) {
    Serial.print("address: 0x");
    Serial.println(addressList[i][0], HEX);
    Serial.print("buttonIndex: ");
    Serial.println(buttonIndex);
    //Determine number of bytes for buttons
    uint8_t requestBytes = addressList[i][1]/8 + addressList[i][2];  //[i][1]/8 gets number of buttons, [i][2] is number of rotaries
    if (addressList[i][1]%8) {
      requestBytes++;
    }
    Wire.requestFrom(addressList[i][0], requestBytes);
    uint8_t buttonCount = addressList[i][1];
    uint8_t rotaryCount = addressList[i][2];
    while (Wire.available()) {
      byte tempByte = Wire.read();
      Serial.print("  Byte - 0x");
      Serial.println(tempByte, HEX);
      if (buttonCount) {
        for (uint8_t j = 0; j < 8; j++) {
          //cycle through buttons, individually setting state
          Joystick.setButton(buttonIndex, (tempByte&(0x01<<j)));
          buttonIndex++;
          buttonCount--;
        }
      } else if (rotaryCount) {
        writeJoystickValue(tempByte, rotaryIndex);
        rotaryIndex++;
        rotaryCount--;
      }
    }
  }
  delay(50);
  millisecondsSincePing += 50;
  if (millisecondsSincePing >= PING_FREQUENCY) {
    ping_bus();
    millisecondsSincePing = 0;
  }
}

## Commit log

2021-07-14 Actual initial commit
    [Backside.SLDPRT, Frontside.SLDPRT, LongButton.SLDPRT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]
2021-07-22 Removing panelisations, adding polyfuses
    [MFD-panel-B_Cu.gbr, MFD-panel-B_Mask.gbr, MFD-panel-B_Paste.gbr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]
2021-08-11 MCAD updates
    [Backside.SLDPRT, Backside.STL, Frontside.STL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]
2021-08-12 Change from 1x04 2.54mm headers to 1x05 micro JST
    [MFDint-option2.kicad_pcb, MFDint-option2.sch, MFDintbutton.kicad_pcb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]
2021-08-12 Add JST connector and FTDI connector to MFD-child. Also, fix some submodule issues?
    [MFD-child.kicad_pcb, MFD-child.sch]
2021-08-17 Swap bus connector to 4-pin JST-GH
    [MFD-child.kicad_pcb, MFD-child.sch, MFDint-option2.kicad_pcb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]
2021-08-17 Whoops, forgot the master board
    [i2c-master.kicad_pcb, i2c-master.sch]
2021-08-20 5-pin -> 4-pin JST
    [i2c-master-B_Cu.gbr, i2c-master-B_Mask.gbr, i2c-master-B_Paste.gbr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]
2022-02-04 major update, MCAD and some programs
    [Backside.SLDPRT, ButtonBox-Assembly.SLDASM, ButtonBox-Bottomplate.DXF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]
2022-02-06 Updates given laser cutting realities
    [ButtonBox-Bottomplate.SLDPRT, Master-Back.DXF, Master-Back.SLDPRT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]
